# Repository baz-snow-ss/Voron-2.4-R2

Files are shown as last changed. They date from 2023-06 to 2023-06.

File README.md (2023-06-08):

# Voron-2.4-R2
### 3D Printer


- Sunlu Filament Dryer Box S2
- 350mm FormBot kit
- Logitech C270 HD Cam whit a Apexel Universal Phone Cameras Lens Kit 0.45X Wide Angle Lens 140°+ 12.5X Macro Lens Clip-on

 - Stealthburner toolhead
 - LGX Lite extruder
 - BTT SB2209 CanBus board
 - Chaoticlabs Tap
 - Phaetus Rapido
 - Noctua NF-A4x10 PWM, Premium Quiet Fan, 4-Pin (40x10mm, Brown)
 - GBA-SZC 3010 Cooling Fan 24V DC
  
- 2x 24v LED Case light Strips 6-6500k
- Chamber Temperature Probe HT-NTC 100k
- 4x Spherical bearing mod M5 on the Z gantry
- Manta MP8 Board / CB1 / TMC2209

- BTT HDMI5
- Micro HDMI to HDMI cable 3ft'
- 90' HMDI Adatpter
- 90' USB-C Adapter
- BTT 1.2v Relay

- NeverMore x2 5015 blower fan 24v
- Filter Box Mod
- CP-6005 Cut to fit Carbon Pad
- CSKB Hepa Filter for the IRobot Roomba 
- Noctua NF-F12 iPPC-2000, Heavy Duty Cooling Fan, 3-Pin, 2000 RPM (120mm, Black)

### Reference:

https://www.klipper3d.org/Overview.html

https://github.com/VoronDesign/Voron-Tap/tree/main
https://github.com/bigtreetech/Manta-M8P/issues/30#issuecomment-1429197885
https://www.klipper3d.org/CANBUS.html

https://github.com/bigtreetech/EBB/tree/master

https://docs.meteyou.wtf/btt-ebb/

https://github.com/Esoterical/voron_canbus  A very well documented github this was a life saver!!!

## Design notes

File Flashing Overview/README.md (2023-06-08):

This is the procedure we follow for getting CANBUS working on the Manta MP8 v1.1s/CB1:

1. Mainboard flashing BTT Manta M8P with CB1 v1.1 
2. Flash CanBoot
3. Klipper Config uses USB-CAN-Bridge
4. Install Klipper
5. Configure interface.d 
6. Toolhead Flashing BTT SB2209 CanBus
7. Installing CanBOOT
8. CanBOOT Config
9. Installing Klipper
10. Retrive the two UUID's for your config
11. Add the configuration of this motherboard in the "printer. cfg" file:

Create and Edit the CanBus Network file.
```
sudo nano /etc/network/interfaces.d/can0
```
```
allow-hotplug can0
iface can0 can static
 bitrate 1000000
 up ifconfig $IFACE txqueuelen 1024
 ```
 Hit Q and Y

Edit the printer.cfg enter the correct CanBus UUID 
```
[include sb2209-canbus.cfg]
[mcu]
#serial /dev/serial/by-id/usb-Klipper_firmware_12345-if00
canbus_uuid: f7ee535c8aa0
```
Create sb2209-canbus.cfg or what ever you wish to name it.
```
## sb2209-canbus.cfg
[mcu EBBCan]
canbus_uuid: 1e0d36d3d925
```

image png 01dca6a9cf7c28244cc9e473025b6ffc
### Entering DFU Mode
1. Connect the USB cable from the CB1/Pi and insert the 5V Jumper
2. Press and hold the `RESET` and `BOOT` buttons down
3. Release `RESET` button
4. Release `BOOT` button
5. The device should now be in DFU mode. Verify this via the `lsusb` command, which should look something like this:

```
Bus 001 Device 005: ID 0483:df11 STMicroelectronics STM Device in DFU Mode
```

Wire up the CAN bus using a twisted pair between the manta and your other boards.
See the Manta M8P v1.1 pinout on page 11 of the manual.
The M8P V1.1 has two identical CAN ports that are [ CAN-L, CAN-H ], [ CAN-L, CAN-H ]

Pins: L (PD12) / H (PD13)

Wire the power  Directly to the power supply 24v
Make sure to verify that you have 120ohm resistors terminating the bus, and that your other boards

are flashed for CANBUS communication at the same speed (1000000)
NOTE: when using CANBus you need to use a Jumper on the 120R Jumper on the SB2209 (and the Mainboard M8P)

Configure the module's specific functions according to your parts, and needs.

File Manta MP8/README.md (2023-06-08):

## Mainboard flashing BTT Manta M8P with CB1 v1.1

Enter DFU Mode on the mainboard  `Boot` `Reset`
```
cd ~/CanBoot
make menuconfig
```
### CanBOOT Config (note this just uses the default USB communication interface)
image png ad03682ba08fc79626c8fd0432e13b16
```
make clean
make
dfu-util -l
```
image thumb png afcb3c1f386455718f5aecbdece78502
```
dfu-util -R -a 0 -s 0x08000000:force:mass-erase:leave -D ~/CanBoot/out/canboot.bin -d 0483:df11
```
image thumb png 9353a8be076226ee599728a395a32864
CanBoot is Now flashed, Flashing klipper via CanBOOT will be covered shortly.
```
cd ~/klipper/
make menuconfig
```
### Klipper Config uses USB-CAN-Bridge
image png b60a7a91ac433f5bbc54ac4b7e1b8446
```
make clean
make
```
### If you have CanBOOT installed
```
ls /dev/serial/by-id/
```
image png 50cd3f002a25048e9cd409c0bdd5f51c

Run this command to install klipper firmware via canboot via USB. Use the device ID you just retrieved in the above ls command.
```
python3 ~/CanBoot/scripts/flash_can.py -f ~/klipper/out/klipper.bin -d /dev/serial/by-id/usb-CanBoot_stm32g0b1xx_52002D000D504B4633373520-if00
```
image thumb png cdf77b51d83df188a25103018e2e527f

### If you are running a stock bootloader and flashing via SD card INSTEAD of CanBOOT
Simply follow the mainboard user manual to copy the ~/klipper/out/klipper.bin file to an SD card (renaming it if needed) and flash the mainboard as per user manual.
### If you are flashing via DFU mode (no CanBOOT or stock bootloader)
Then simply run the following commands to change to the klipper directory then flash the mainboard.
```
cd ~/klipper
make flash FLASH_DEVICE=0483:df11
```
where the FLASH_DEVICE ID is the address of the USB device
### Klipper is now installed

This should have now installed klipper firmware to your mainboard. You can verify by running lsusb and you should see a "Geschwister Schneider CAN adapter" or similar device.
image png 7aa5df0bf8b259d6d7d17d17c0bb6ccf
You can also check by running an 'interface config' command ifconfig. If the USB-CAN-Bridge klipper is up and happy (and you have created the can0 file mentioned in the main page) then you will see a can0 interface:
image png 3a2ff9829ff81d4d63392728769c8eb1
You can now run the Klipper canbus query to retrieve the canbus_uuid of your mainboard:
```
~/klippy-env/bin/python ~/klipper/scripts/canbus_query.py can0
```
image png 418bd590f41553179dfd4d9f2fc2c3f9

Use this UUID in the [mcu] section of your printer.cfg in order for Klipper (on Pi) to connect to the mainboard.

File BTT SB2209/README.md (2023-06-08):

[SB2209 build guide PDF](https://github.com/bigtreetech/EBB/blob/master/EBB%20SB2240_2209%20CAN/Build%20Guide/EBB%20SB2240%202209%20CAN%20v1.0%20Build%20Guide.pdf)

## Toolhead Flashing BTT SB2209 CanBus
<p> As mentioned in the main guide, you can either use CanBOOT on your toolhead to facilitate 
  flashing over CAN, or you can go without and have the board boot straight into klipper.</p>

### Installing CanBOOT

```
cd ~
git clone https://github.com/Arksine/CanBoot
```
To configure the CanBoot firmware, run these commands to change into the CanBoot directory and then modify the firmware menu:
```
cd ~/CanBoot
make menuconfig
```
You want the Processor, Clock Reference, and Application Start offset to be set as per whatever board you are running. Make sure "Communication Interface" is set to "CAN bus" with the appropriate pins for your board. Also make sure the "Support bootloader entry on rapid double click of reset button" is marked. It makes it so a double press of the reset button will force the board into CanBOOT mode. Makes re-flashing after a mistake a lot easier.

### CanBOOT Config



```
make clean
make
```
To flash, connect your toolhead board to the Pi via USB then put the toolhead board into DFU/BOOT mode (your toolhead board user manual should have instructions on doing this).

STM32 based board:

To confirm it's in DFU mode you can run the command `dfu-util -l` and it will show any devices connected to your Pi in DFU mode or use `lsusb` .
```
dfu-util -R -a 0 -s 0x08000000:force:mass-erase:leave -D ~/CanBoot/out/canboot.bin -d 0483:df11
```


### CanBOOT is now installed

CanBOOT should now be successfully flashed. Take your toolhead out of DFU mode (it might require removing jumpers and rebooting, or just rebooting).

Wire up your toolhead power (24v and gnd) and CAN (CANH/CANL) wires, then the following command to see if the toolhead board is on the CAN network and waiting in CanBOOT mode
```
python3 ~/CanBoot/scripts/flash_can.py -i can0 -q
```
You should see a "Detected UUID" with "Application: CanBoot"
image png 4f105b5a3ffc5e8cc67c9b1901152288

If you see the above, take note of the UUID and move on to flashing Klipper to the toolhead board.

### Installing Klipper
```
cd ~/klipper/
make menuconfig
```
### Klipper when using CanBoot
image png 623b5ea3ee63b57129722a63d5995593
```
make clean
make
```
If you have CanBOOT installed
Run 
```
python3 ~/CanBoot/scripts/flash_can.py -i can0 -q
```
and take note of the CanBoot device that it shows:

image png c56466210e61117764737cb42fa483ad
Then run the following command to install klipper firmware via CanBOOT. Use the UUID you just retrieved in the above query.
where the "-u" ID is what you found from the "flash_can.py -i can0 -q" query.
```
python3 ~/CanBoot/scripts/flash_can.py -i can0 -u 1e0d36d3d925-f ~/klipper/out/klipper.bin
```
image thumb png 8ff659ce12531da2caca5b5f040a3967
One the flash has been completed you can run the
```
python3 ~/CanBoot/scripts/flash_can.py -i can0 -q
```
command again. This time you should see the same UUID but with "Application: Klipper" instead of "Application: CanBoot"

### If you don't have CanBOOT installed
Then simply run the following commands to change to the klipper directory then flash the toolhead board.
```
cd ~/klipper
make flash FLASH_DEVICE=0483:df11
```
where the FLASH_DEVICE ID is the address of the USB device you noted down above.

### Klipper is now installed
You can now run the Klipper canbus query to retrieve the canbus_uuid of your toolhead board:
```
~/klippy-env/bin/python ~/klipper/scripts/canbus_query.py can0
```
image png 33196036442d0b3582c70bd9d6d0d926

NOTE when using CANBus you need to use a Jumper on the 120R Jumper on the SB2209 (and the Mainboard M8P in my example)

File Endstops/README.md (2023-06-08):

### Wiring End Stops
c754031926eb4f4ea1a9c7ecbcfd5318
1eed2b93114540ddb6c84c9f8e0066f0

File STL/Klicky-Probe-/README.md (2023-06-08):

# Klicky Probe
Microswitch probe with magnetic attachment, primarily aimed at CoreXY 3d printers.

Initially it was focused on the [Voron printers](https://vorondesign.com/) (V2.4, V1.8, Trident, V0) and derivatives, now it's been restructured to better allow other printers to be documented [on the main repository](https://github.com/jlas1/Klicky-Probe)

The objectives for this project are:

- drop in replacement for Omron TL-Q5MC2 or PL-08N2 (you don't need to replace the toolhead), replacement of BLtouch probes
- soldering not required
- minimal adjustments required
- be able to detect all the print surfaces
- be as close to the hotend tip as possible
- highly repeatable and accurate probes
- less temperature variations
- no melting of its parts
- cheap to build
- reuse spare parts if possible

Most of the Klicky probe users are using klipper, there are some macros in here that ease the probing process, by automating the attach, dock and use of the probe.

Some work has been developed to have the same functionality on RRF.

It can also be used with the [automatic Z calibration](https://github.com/protoloft/klipper_z_calibration) klipper plugin to effectively calculate the Z offset from the probe and from the Z endstop if your printers supports a Z endstop triggered by the nozzle (like most Voron's do)

The inspiration for the Klicky Probe comes from the [Quickdraw](https://github.com/Annex-Engineering/Quickdraw_Probe) and the [Euclid probe](https://github.com/nionio6915/Euclid_Probe), it uses some concepts from each of the projects.

Updated instructions provided by StefanRaatz.
oc_geek and TurBoxxs were also a great help in refining and testing the CAD files.
Garrettwp provided the initial revised macro files.
User richardjm revised the macro variables and added some functions.
Mental created the initial macro and one of the first magnetically attached microswitch probes.

Without them, and some others this effort would not be in the current state, many thanks to them all.

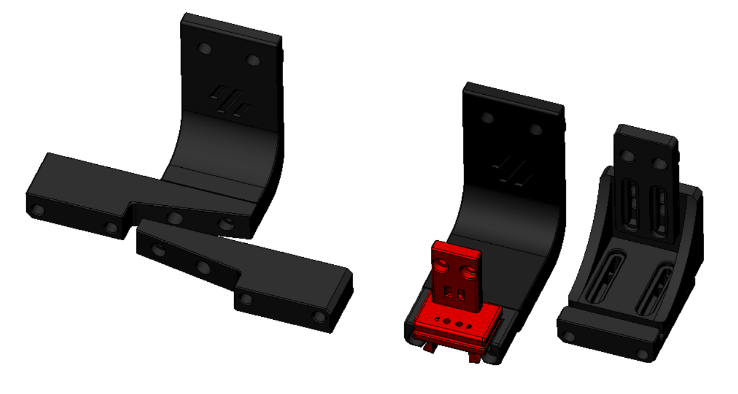
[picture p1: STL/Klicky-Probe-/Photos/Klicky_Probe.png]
Klicky Probe image
If you want to donate something regarding this project, use this [link](https://paypal.me/Josar154) or [__Buy me some ABS!__](https://www.buymeacoffee.com/JosAr), thank

klicky early version.

# Upgrading from an earlier version

If you are upgrading from an earlier version, check the [klipper macros](https://github.com/jlas1/Klicky-Probe/tree/main/Klipper_macros) folder, it contains update instructions.

# Klicky components

All the compatible printers require:

* Toolhead mount (the thing that the probe attached to when it's being used)
* Klicky probe (there are three versions, all are interchangeable and compatible, more information on the specific printer page), what actually is used to probe the bed
* Probe dock (all the printers use the same)
* Probe dock mount (what attaches to the printer to dock the probe when not in use)

The CAD with all the files is located [Here](./CAD)

Common Klicky STL's (parts that are common to all the printers)  are located [here](./Base_STL).
Printer specific STL are in each printer directory.

The klipper macros are [here](https://github.com/jlas1/Klicky-Probe/tree/main/Klipper_macros), the RRF [here](https://github.com/jlas1/Klicky-Probe/tree/main/RRF_macros).

## Probe accuracy

The probe accuracy output is better than a range of 0.025mm (difference between highest and lowest), and a standard deviation of 0.01mm.

## Print Settings

There are no need for supports, recommended settings are 4 perimeters/top/bottom, at least 23% infill, the STL's are already oriented, you only need to send them to the slicer.

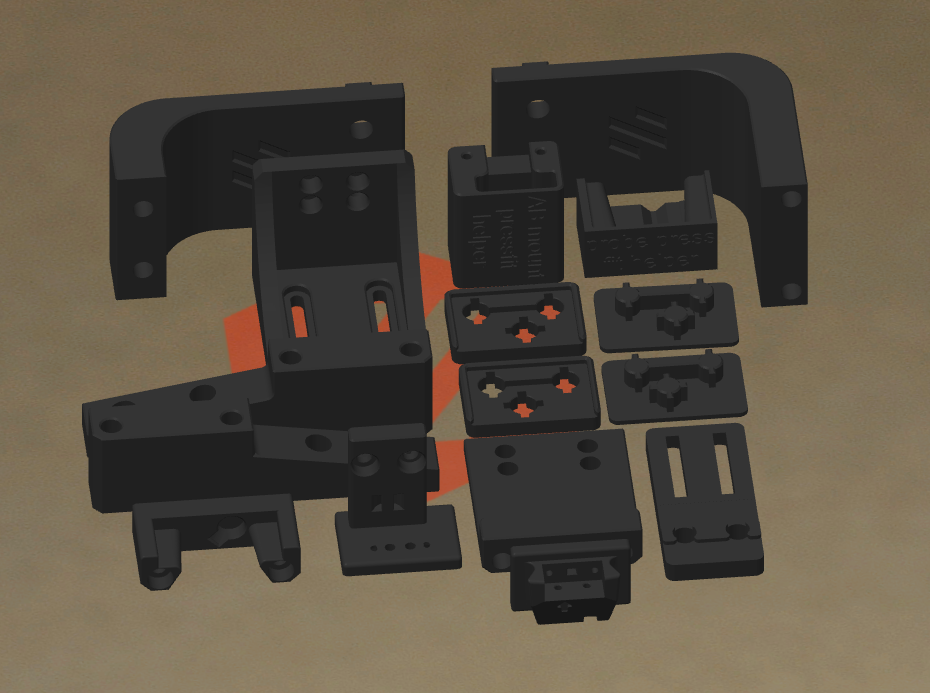
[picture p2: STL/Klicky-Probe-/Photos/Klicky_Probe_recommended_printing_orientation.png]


Each printer family/version has it's own mounting options, Bill of Materials, assembly instructions and dock/attach setup.

# General Bill of Materials (BOM)

Tools:

- 1.5mm Drill (optional)
- Multimeter to check for Continuity 
- Super Glue
- Soldering Iron for the heat inserts

Probe BOM:

- 1x microswitch (the omron D2F-5 or D2F-5L (removing the lever) is recommended), D2F-1 and similar sizes microswitch also work
- 2x M2x10 mm self tapping
- some 6 mm x 3 mm magnets (it ranges from 8 to 10)
- some m5 screws
- some m3 screws
- some m3 heat inserts
- some m3 nuts

## Printers supported on other locations

There are several micro sized Voron variants, most also support klicky, you can find more information on the site https://3dprintersforants.com/

# Assembled Klicky Probe on a Voron v2.4

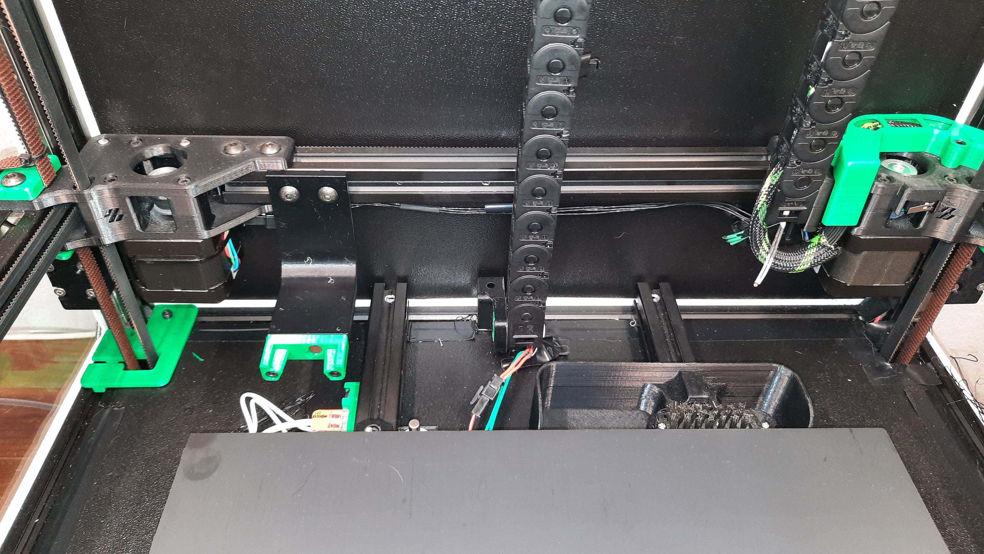
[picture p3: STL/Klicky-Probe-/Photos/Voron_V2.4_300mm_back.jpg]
Assembled Klicky Probe
# 

It is working very well, if you decide to use it, give me feedback, either here, or on Voron discord, my discord user is JosAr#0517.

By standing on the shoulders of giants, lets see if we can see further.

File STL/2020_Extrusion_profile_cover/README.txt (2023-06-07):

2020 Extrusion profile cover (Nut 6) by anton610 on Thingiverse: https://www.thingiverse.com/thing:1478147

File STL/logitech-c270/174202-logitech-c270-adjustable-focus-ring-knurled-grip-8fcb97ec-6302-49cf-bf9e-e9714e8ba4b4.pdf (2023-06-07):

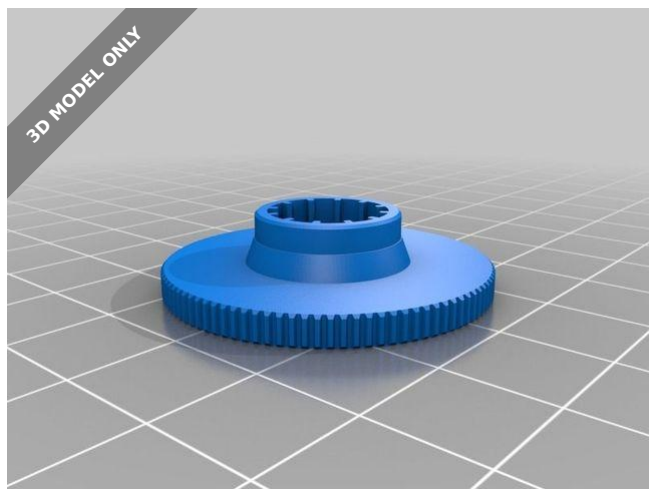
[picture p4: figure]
3D MODEL ONLY

# Summary

I was unable to find good models that could be used a easier to modify

model of the focusing ring, mainly because I...

3D Printers (https://www.printables.com/model?categoryId=1) | > | Accessories (https://www.printables.com/model?categoryId=40)
Tags: | fusion360 | logitechc270

I was unable to find good models that could be used a easier to modify

model of the focusing ring, mainly because I found the grip on the ring

very lacking.

So I made one based on measurements taken from the focus ring stl files.

Included is the finished STL file with better grip, as well as a STEP and

Fusion360 file.

## Print Settings

## Printer Brand:

Prusa

## Printer:

### i3 MK3

## Graloth (https://www.printables.com/social/2104/about)

# Logitech C270

# adjustable focus

# ring knurled grip

VIEW IN BROWSER (https://www.printables.com/model/174202-logitech-c270-adjustable-focus-ring-knurled-grip)

updated 18. 4. 2022 | published 18. 4. 2022

# Model files

# Other files

## Rafts:

No

## Supports:

No

## Resolution:

0.20mm

# Infill:

15%

Category: 3D Printer Accessories

Find source .stl files on Thingiverse.com (https://www.thingiverse.com/thing:3088614)

### focus_ring.step

### focus_ring.f3d

### focus_ring.stl

### sources.txt

# License

This work is licensed under a

Creative Commons (4.0 International License)

Attribution-ShareAlike (http://creativecommons.org/licenses/by-sa/4.0/)

### ✖ | Sharing without ATTRIBUTION

✔ | Remix Culture allowed
✔ | Commercial Use
✔ | Free Cultural Works
✔ | Meets Open Definition

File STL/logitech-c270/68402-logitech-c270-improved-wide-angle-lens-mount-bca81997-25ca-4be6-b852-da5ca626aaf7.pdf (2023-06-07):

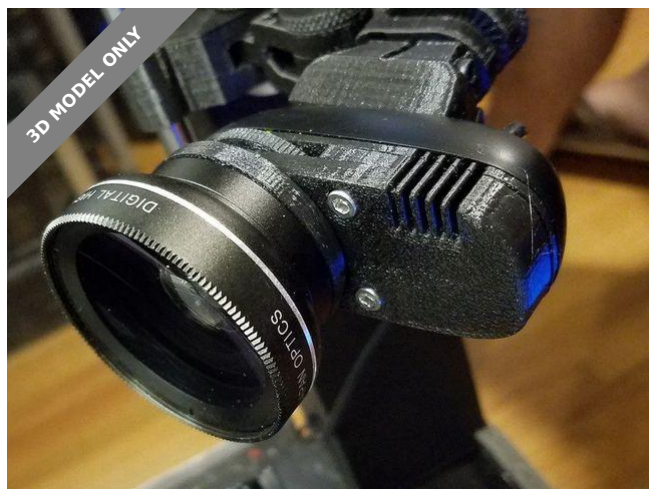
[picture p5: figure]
3D MODEL ONLY

# Summary

I updated CO-OCD's great design for the Logitech C270 by adding threads

and air vents. After I started printing...

3D Printers (https://www.printables.com/model?categoryId=1) | > | Accessories (https://www.printables.com/model?categoryId=40)
Tags: logitech | c270 | c270mount | logitechc270

I updated CO-OCD's great design for the Logitech C270 by adding threads

and air vents. After I started printing polycarbonate in my enclosure at

around 38C ambient my entire C270 setup started warping. See the last 2

photos for the warping of my original parts.

This could be due to two reasons:

I used HTPLA which the ambient + camera might overheat so I

reprinted in PETG

The camera generates a lot of internal heat so I added air vents to

the case Additionally with the weight of the wide angle lens I could no

longer trust the push fit design, so I added threads to both ends of

the wide angle lens mount. This is much more secure. You will need to

get a focus ring from another design upload. I use this one: https://

www.thingiverse.com/thing:3088614

Category: 3D Printer Accessories

Z (https://www.printables.com/social/245/about) Zcubed (https://www.printables.com/social/245/about)

# Logitech C270 Improved Wide angle Lens Mount

VIEW IN BROWSER (https://www.printables.com/model/68402-logitech-c270-improved-wide-angle-lens-mount)

updated 12. 4. 2022 | published 3. 6. 2021

1.

2.

# Model files

Find source .stl files on Thingiverse.com (https://www.thingiverse.com/thing:3682691)

# License

This work is licensed under a

Creative Commons (4.0 International License)

Attribution-NonCommercial (http://creativecommons.org/licenses/by-nc/4.0/)

✖ | Sharing without ATTRIBUTION
✔ | Remix Culture allowed
✖ | Commercial Use
✖ | Free Cultural Works
✖ | Meets Open Definition

case_front_with_vents.stl

threaded_lens_adapter.stl

case_back_with_vents.stl

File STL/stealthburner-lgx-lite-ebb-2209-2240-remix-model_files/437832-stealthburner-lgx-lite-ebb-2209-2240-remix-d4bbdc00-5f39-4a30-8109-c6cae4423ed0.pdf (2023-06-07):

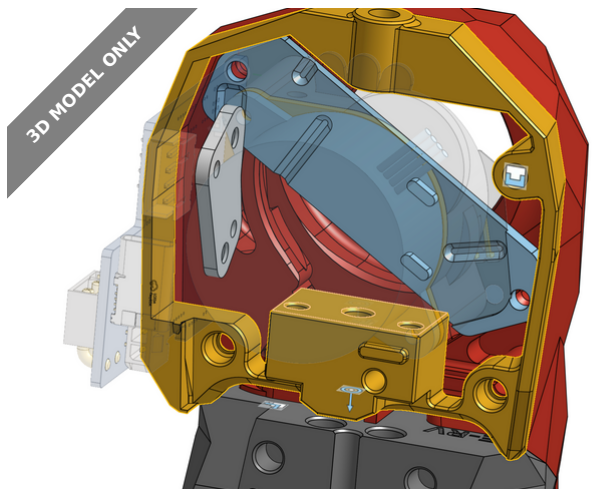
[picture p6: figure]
3D MODEL ONLY

Summary

Various fixes to make this model assemble

3D Printers (https://printables.com/model?categoryId=1) > 3D Printers - Upgrades (https://printables.com/model?categoryId=2)

The original models of the EBB boards seem to be inaccurate to the as-delivered boards. This results in an incorrect assembly and bad parts. I've tweaked the EBB models based on measurements and sample prints so that it assembles without any apparent issues.

Note that you will need to trim the pins on the back of the daughter board down to 1mm. The boards come with some of the pins trimmed and some left long. Check the fit with the carrier plate.

Fixes & Alterations

Probably 15 rounds of print and fit to get the boards to fit inside all of the parts.
Fixed self tapping screw locations to be 2.8mm
Rebuilt the board mounting adapter that connects the main EBB board to the LGX Lite
Fixed locations with FHCS screws not having an ISO standard geometry and being proud of the surface.
Created a carrier plate to mount the daughter board onto for secure mounting

g (https://printables.com/@garethky_1988) gareth.ky (https://printables.com/@garethky_1988)

Stealthburner / LGX

## Lite / EBB 2209 & 2240 - Remix

VIEW IN BROWSER (https://printables.com/model/437832-stealthburner-lgx-lite-ebb-2209-2240-remix)

updated 7. 4. 2023 | published 7. 4. 2023

•

•
•

•

•

Fixed the geometry of the bowden tube hole so it actually works as originally designed by Bondtech.
Cut a hole all the way through to the LGX Lite so its a single piece of PTFE tube from the hot end to there and no printed parts guiding the filament.
Removed a filet the cable cover that was colliding with the EBB board. The cable cover now comes in 3 variants: No Fan, 30mm Fan and 40mm Fan.
Removed the nozzle cam geometry and merged the ugly outline parts back together so it looks like original stealth burner.

Print/Build Notes

The screws that attach EBB board to the adapter on the LGX Lite need to be 5mm long. Its not a common size, 4mm will work in a pinch. Longer will push the board out or strip the hole.

Photos show how to attach the EBB 0000 board to the carrier late. The plate holds the fan in too.

The little leaver cap thing is touch to get a good print of. Laying flat results in a loose print. Vertical runs the risk of the layers splitting. My best results are with PC filament and the vertical orientation with the hole facing down and a brim (as is set up in the 3MF).

Resources

CAD Link with a full working assembly: https://cad.onshape.com/documents/106aa1773b40f1e1a29c0668/w/0ba9143aa216d4395aec8a0f/e/1689c175c7d59b83f1e95de3 (https://cad.onshape.com/documents/106aa1773b40f1e1a29c0668/w/0ba9143aa216d4395aec8a0f/e/1689c175c7d59b83f1e95de3)

Sources (as best as I can work out from the original work by @Pierre_1862):

EBB board CAD (https://github.com/bigtreetech/EBB/tree/master/EBB%20SB2240_2209%20CAN/SB2240/3D)
Voron Stealthburner (https://github.com/VoronDesign/Voron-Stealthburner)
LGX_Lite_Stealthburner_CW2_style_mount (https://github.com/Eytecz/LGX_Lite_Stealthburner_CW2_style_mount)

This remix is based on

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
nozzle
cam &
LGX lite
& BTT
SB2209
&
umbilical (https://printables.com/@Pierre_1862)
mod

2.4 -
Stealthburner
with
3DO
nozzle
cam &
LGX lite (https://printables.com/model/412909-voron-24-stealthburner-with-3do-nozzle-cam-lgx-lit)
& BTT
SB2209
&
umbilical
mod

Voron
2.4 -
Stealthburner (https://printables.com/model/412909-voron-24-stealthburner-with-3do-nozzle-cam-lgx-lit)
with
3DO (https://printables.com/@Pierre_1862)
nozzle
cam &
LGX lite
& BTT
SB2209
&
umbilical
mod

## Model files

Voron 2.4 - Stealthburner with 3DO nozzle cam & LGX lite & BTT SB2209 & umbilical mod (https://printables.com/model/412909-voron-24-stealthburner-with-3do-nozzle-cam-lgx-lit)
by Pierre (https://printables.com/@Pierre_1862)

License

This work is licensed under a GNU

General Public License v3.0 (https://www.gnu.org/licenses/gpl-3.0.html)

✖ | Sharing without ATTRIBUTION
✔ | Remix Culture allowed
✔ | Commercial Use
✔ | Meets Open Definition
ℹ | Share under the same license

lgx_lite_ebb_22xx_mod.3mf

lgx_lite_ebb_22xx_mod_all_parts.step

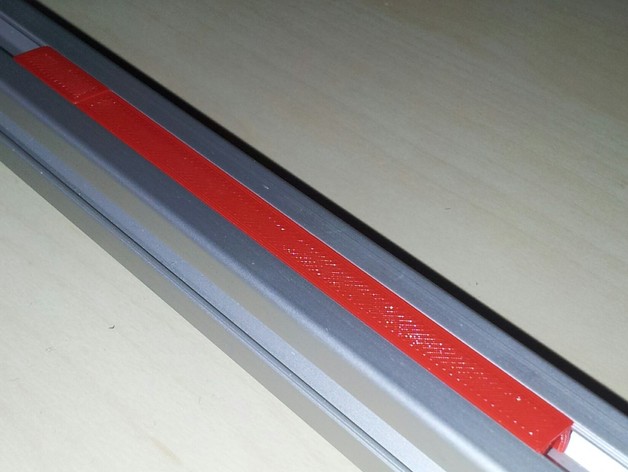
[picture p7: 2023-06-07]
STL/2020_Extrusion_profile_cover/images/74855288e9e5f11b7890737bd30bf6a0.jpg

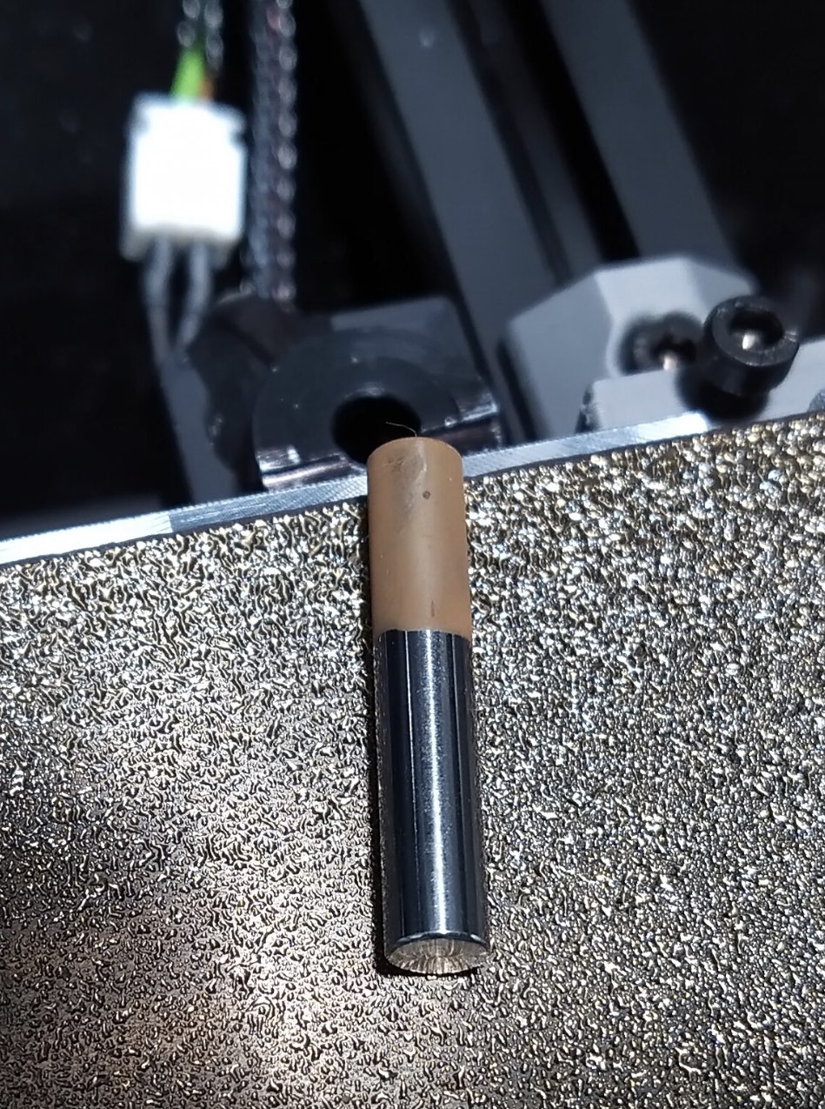
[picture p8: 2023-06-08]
STL/Nevermore_Micro-master/images/endstop-switch-acid-residue.jpg

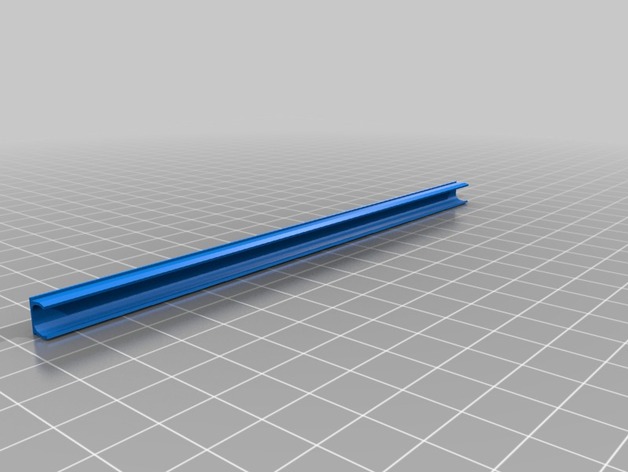
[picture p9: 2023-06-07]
STL/2020_Extrusion_profile_cover/images/Nut_6_Abdeckung_-_150.jpg

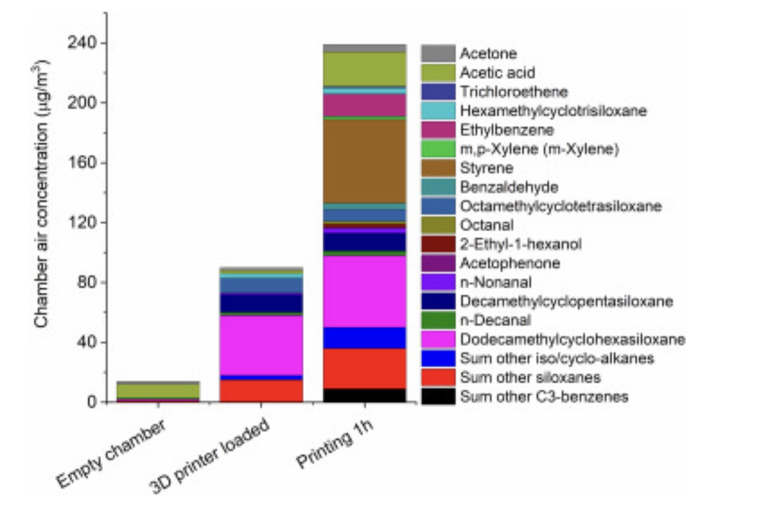
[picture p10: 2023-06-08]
STL/Nevermore_Micro-master/images/emitted-voc3.jpg

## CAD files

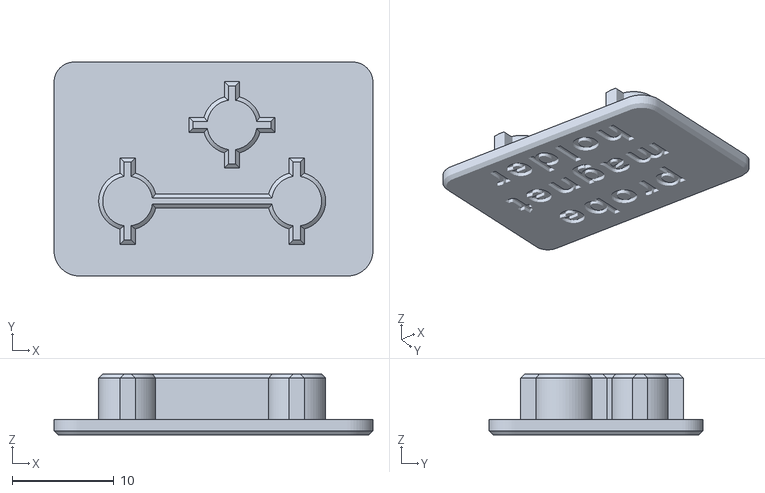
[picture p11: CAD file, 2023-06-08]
STL/Klicky-Probe-/Base_STL/Base_STL/Probe_magnet_pressfit_helper.stl
31.4 x 21.1 x 6.00

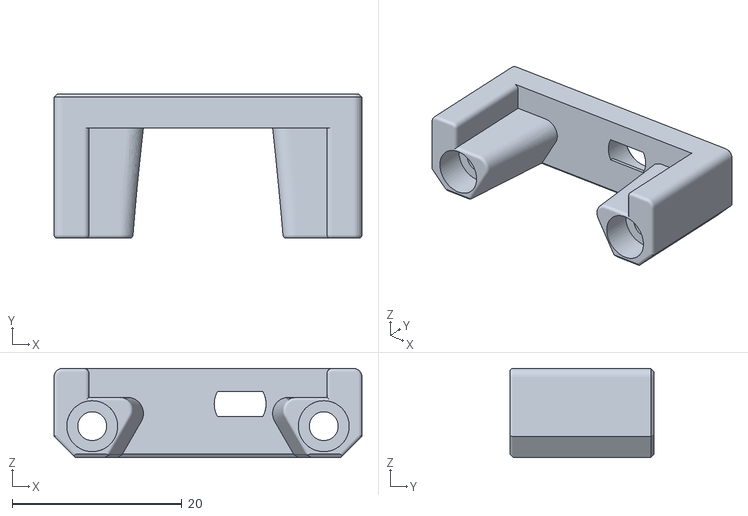
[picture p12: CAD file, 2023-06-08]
STL/Klicky-Probe-/Base_STL/Probe_Dock_v2.1.stl
36.3 x 17.0 x 10.5

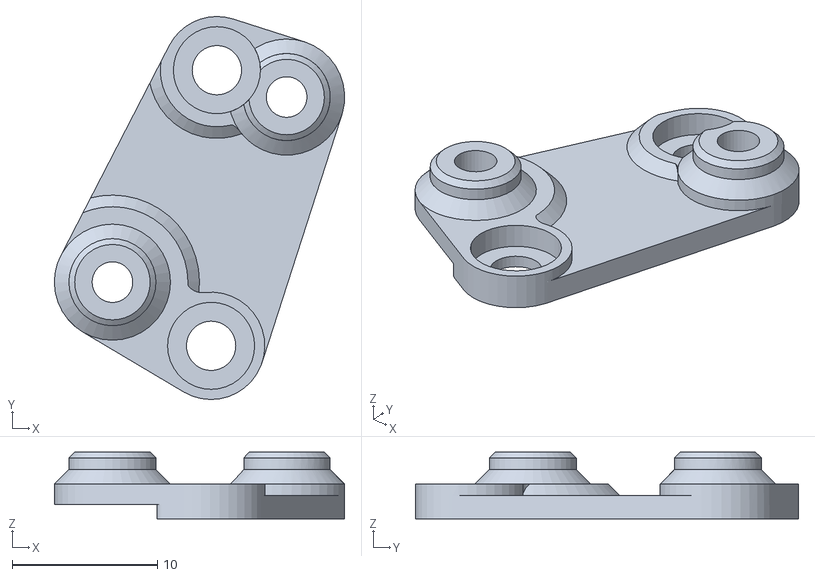
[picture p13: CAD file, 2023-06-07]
STL/LGX Stealthburner/Staffa_LGX_Lite_Tollboard_V14.STL
20.0 x 26.4 x 4.60

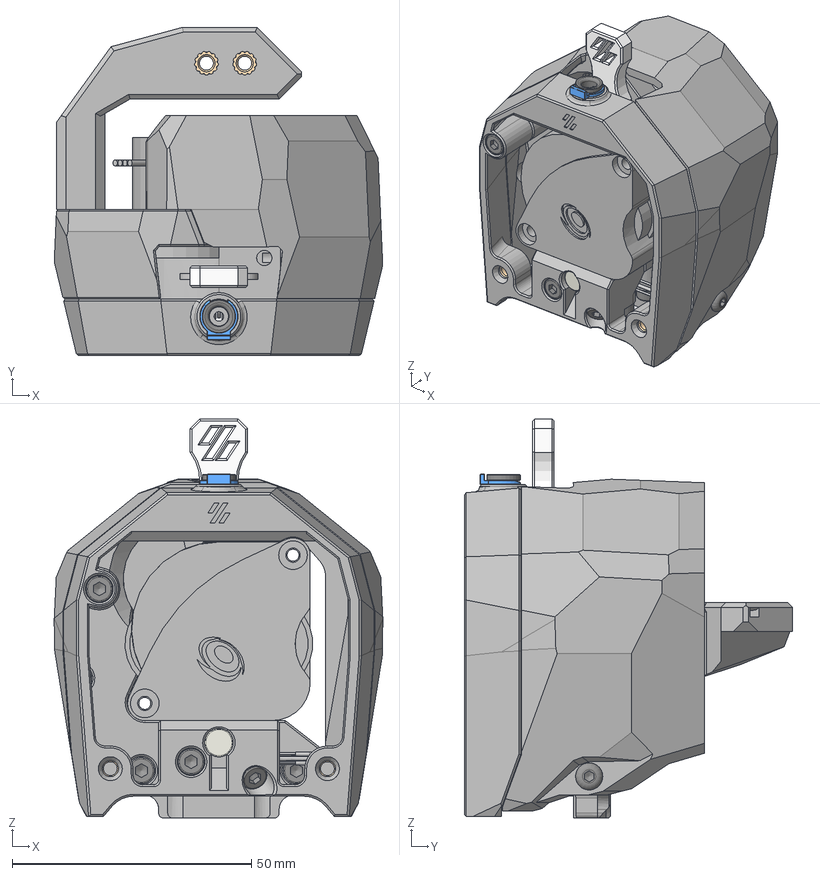
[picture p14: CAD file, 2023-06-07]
STL/LGX_Lite_Stealthburner_ERCF/STEP/LGX_Lite_Stealthburner_ERCF_rev01.stp
68.7 x 68.6 x 83.4 mm
LGX-Lite Dummy
Front_body_LGX_Lite_Stealthburner_ERCF_Released_rev01
Rear_body_LGX_Lite_Stealthburner_ERCF_Released_rev01
[a]_Tension_rocker_LGX_Lite_Stealthburner_ERCF_rev01
Magnet6x3 v1
M3 THREADED INSERT x 9
AH3364Q-P-B v1
M3 Washer
Tube clip^E3D Revo 6
Circlip^E3D Revo 6
chain_anchor_2hole
cable_cover
ISO 7380-1 - M3 x 6
ISO 4762 - M3 x 10 x 2
ISO 4762 - M3 x 8 x 2
ISO 4762 - M3 x 25 x 2
ISO 4762 - M3 x 20
ISO 4762 - M3 x 16 x 4
ISO 4762 - M3 x 12

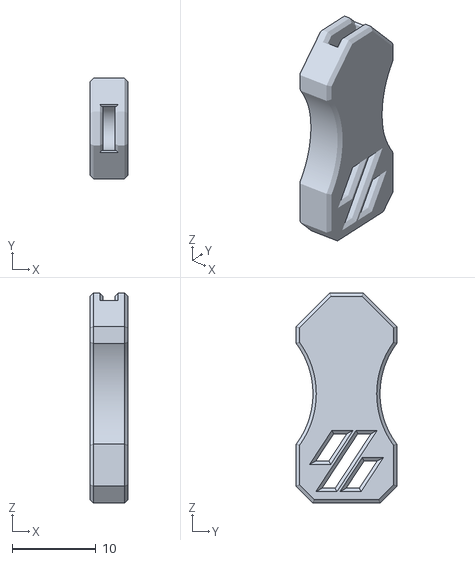
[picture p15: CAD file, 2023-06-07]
STL/LGX_Lite_Stealthburner_ERCF/STL/[a]_Tension_rocker_LGX_Lite_Stealthburner_ERCF_rev01.stl
4.50 x 12.0 x 25.0

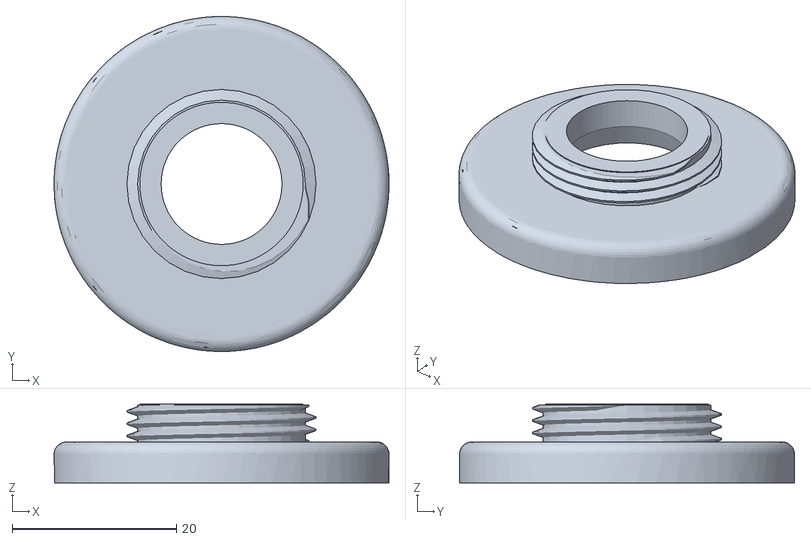
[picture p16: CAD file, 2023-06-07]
STL/logitech-c270/threaded_lens_adapter.stl
40.7 x 40.7 x 9.60

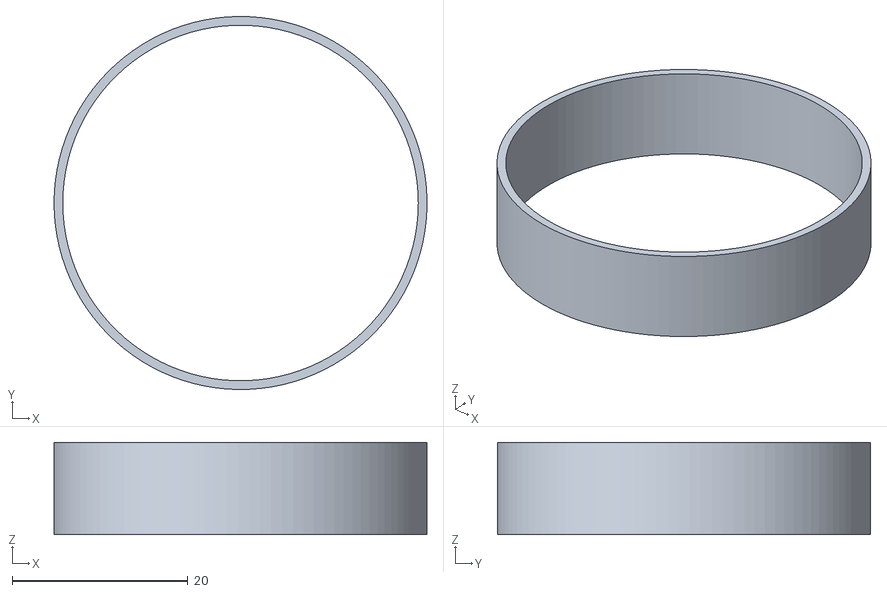
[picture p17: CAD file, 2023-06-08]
STL/Nevermore_Micro-master/V4/cut_guide_optional.stl
42.5 x 42.5 x 10.5

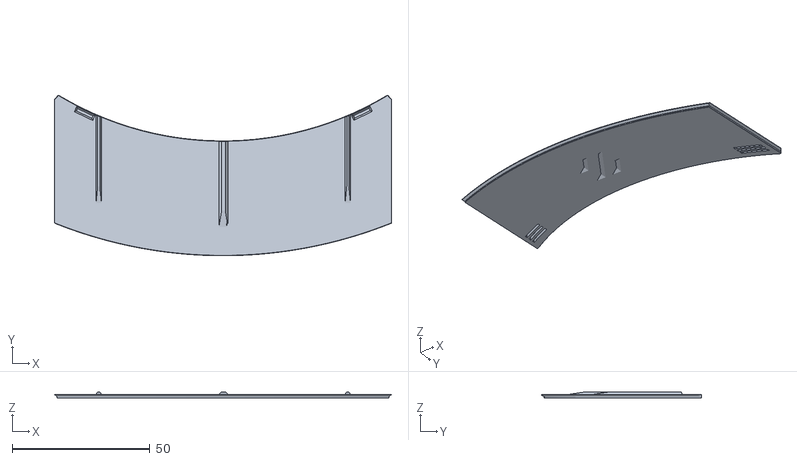
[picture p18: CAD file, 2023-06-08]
STL/Nevermore_Micro-master/V4/V4_4x6_magnets/FILTER_CARTRIDGE_LID_6_3_DirectedUp.stl
122.5 x 58.3 x 2.34

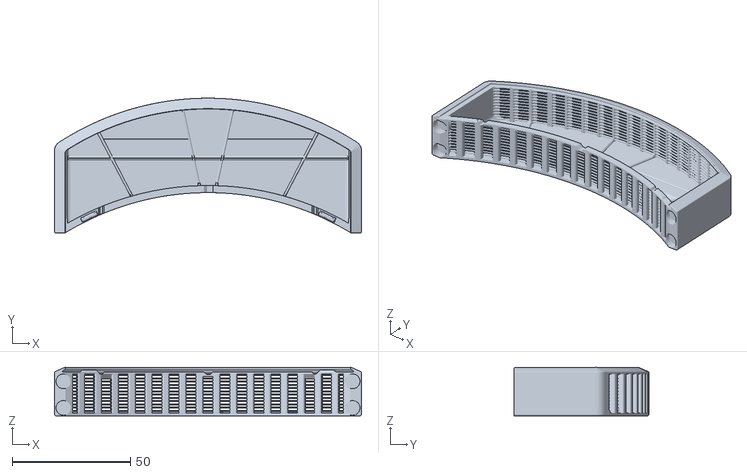
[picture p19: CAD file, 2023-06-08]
STL/Nevermore_Micro-master/V4/V4_6x3_magnets/FILTER_CARTRIDGE_6_3.stl
130.0 x 57.0 x 20.6

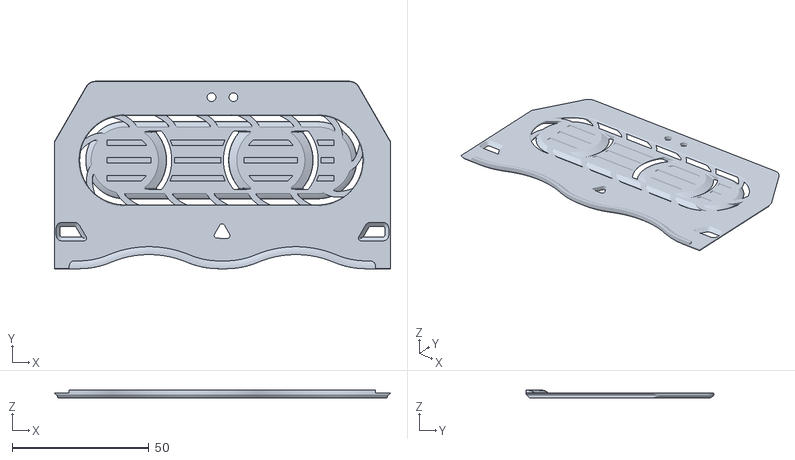
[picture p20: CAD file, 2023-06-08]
STL/Nevermore_Micro-master/V5_Duo/1.8/Plenum_LID.stl
122.8 x 68.5 x 2.80

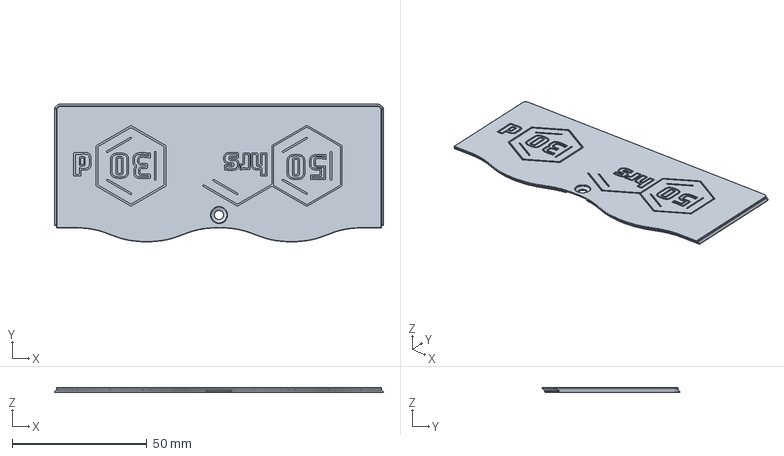
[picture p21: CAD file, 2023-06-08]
STL/Nevermore_Micro-master/V5_Duo/DuoCartridgeLid.step
122.0 x 51.2 x 1.78 mm

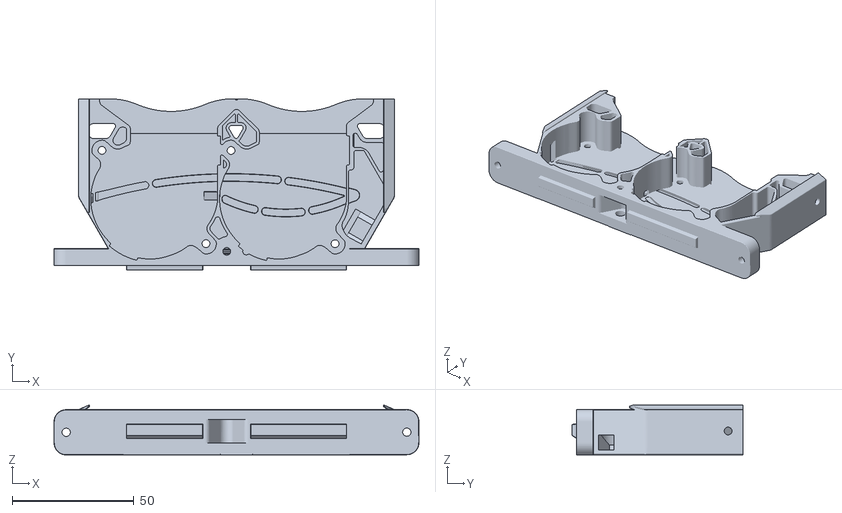
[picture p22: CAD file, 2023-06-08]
STL/Nevermore_Micro-master/V5_Duo/Mods/Rear-Backmount-Plenum_by-mvieleers/mvieleers_nevermore_plenum_backmount.stl
150.0 x 70.5 x 20.5

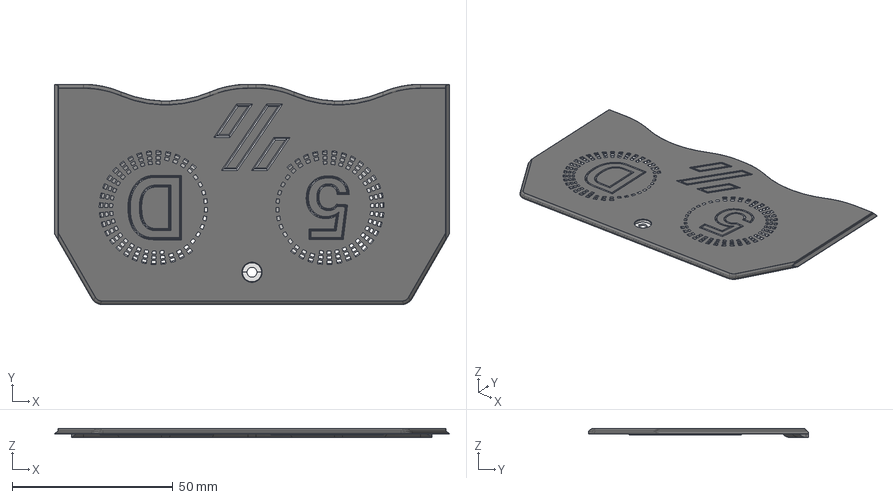
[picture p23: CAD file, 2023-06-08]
STL/Nevermore_Micro-master/V5_Duo/Mods/RLF-35_by_Rama/Testing_Nevermore-RLF35_LID.stp
122.8 x 68.5 x 2.80 mm

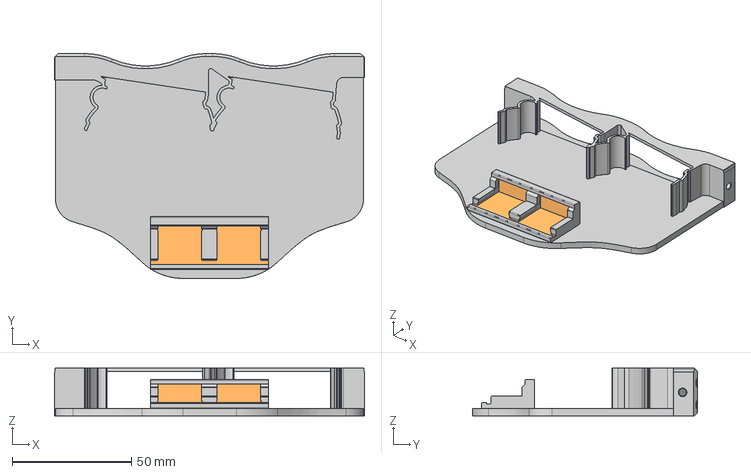
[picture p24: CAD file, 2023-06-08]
STL/Nevermore_Micro-master/V5_Duo/Mods/RLF-35_Wago_&_Less-Plastic_by-Rick/Nevermore_RLF35-v4_Naked_with_triple_Wagos_v5.step
130.0 x 94.3 x 20.0 mm

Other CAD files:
STL/Belt clip/z_belt_clipX4.stl
STL/Nevermore_Micro-master/V5_Duo/Mods/Slide-in-Magnets_by-ChainsDD/Duo_Plenum.step
STL/Nevermore_Micro-master/V5_Duo/V2/V2_Duo_Plenum.stl
STL/stealthburner-lgx-lite-ebb-2209-2240-remix-model_files/LGX_LITE_EBB_22xx_mod.3mf
STL/2020_Extrusion_profile_cover/files/2020_Extrusion_profile_cover.step
STL/2020_Extrusion_profile_cover/files/Nut_6_Abdeckung_-_10.stl
STL/2020_Extrusion_profile_cover/files/Nut_6_Abdeckung_-_100.stl
STL/2020_Extrusion_profile_cover/files/Nut_6_Abdeckung_-_150.stl
STL/2020_Extrusion_profile_cover/files/Nut_6_Abdeckung_-_20.stl
STL/2020_Extrusion_profile_cover/files/Nut_6_Abdeckung_-_200.stl
STL/2020_Extrusion_profile_cover/files/Nut_6_Abdeckung_-_50.stl
STL/Klicky-Probe-/Base_STL/1mm_Spacer.stl
STL/Klicky-Probe-/Base_STL/Base_STL/1mm_Spacer.stl
STL/Klicky-Probe-/Base_STL/Base_STL/KlickyProbe_Long_v2.stl
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

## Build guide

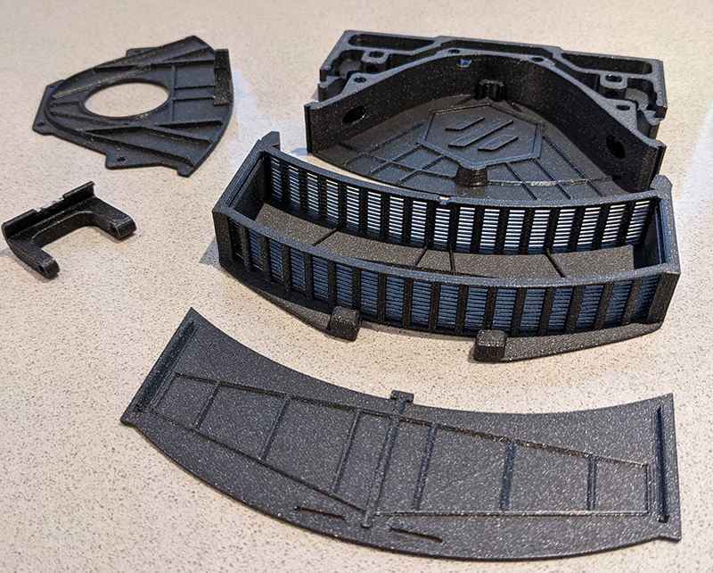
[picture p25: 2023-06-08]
STL/Nevermore_Micro-master/images/print_example2.png
